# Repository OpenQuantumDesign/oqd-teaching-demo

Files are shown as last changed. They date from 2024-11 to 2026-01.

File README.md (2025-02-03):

# Open Quantum Design

<h2 align="center">
    Open Quantum Design: Full-stack Trapped-ion Teaching Demo  
</h2>

> [!NOTE]
> :bangbang: This design is still in the prototype stage - version 3 is under active development. Feel free to get in touch if you're interested in getting access to this teaching tool!

What is a trapped ion quantum computer? What are the components that go into building a quantum computer? What are the layers of a "full-stack"? What does it mean to "trap" an ion?

As quantum computers become increasingly widespread in the world, and as their capabilities advance, teaching an intuitive sense of how these machines work, what they are composed of, and how to interact with them is an important mission. At Open Quantum Design, we aim to democratize access to quantum computing technologies and accelerate a quantum-ready workforce and global community.

## Motivation

We want to provide a tactile and interactive activity for learning about, programming, and building quantum computers. This project contains the designs for a "trapped-ion quantum computer," using low-cost, easily accessible electronics.

## What's inside

The demo traps small beads of polystyrene in an acoustic trap, in analogy to ions in an electromagnetic trap, except visible to the naked eye and can be interacted with. Inexpensive diode lasers are added to demonstrate how the ions are manipulated using light. To demonstrate how the real trapped-ion system is measured using photodetectors, a camera module is included. A Raspberry Pi and Arduino Nano control all of these elements, and a touchscreen display provides a user interface. The enclosure is 3D printed and components assembled.

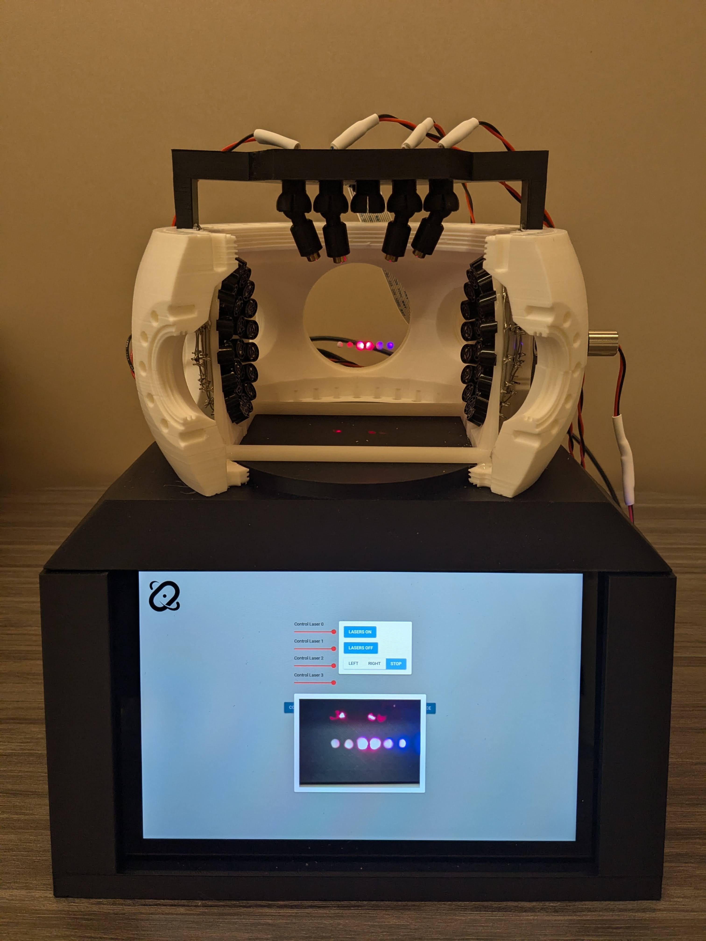
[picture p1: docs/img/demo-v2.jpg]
OQD Demo v2
# 

In the picture of the *version-2* design of the demo unit, six polystyrene balls are suspended in midair by sound. The pressure waves formed by an array of transducers at each end create points where objects are *suspended* in place by the force of the air. While OQD's quantum computers use an electromagnetic potential to trap the ions, the process is quite analogous - and you can actually see the polystyrene beads with your bare eyes, unlike ions! Red and blue lasers, shining onto the "ions," demonstrate how the state of the quantum computer is manipulated and how quantum algorithms are run.

## Want to build your own?

We love to hear that! The current version is still in the prototype stage, and *version-3* is currently in the works. But in this repository, you can find everything you need to build your own trapped ion outreach demo, including the designs, object files to 3D print, electronic wiring diagrams, and the control software.

- [3D printed enclosure components](./design/objects/)
- [Material list](./docs/materials.md)
- [Software](./src/)

## More about quantum computers

Quantum computers utilize the effects of quantum mechanics to process information. Some of the most important effects of quantum mechanics for computing purposes are superposition, entanglement, and measurement.

- **Superposition**: When a quantum particle can be in two distinct states, e.g., spin-up or spin-down, it can also exist in a superposition of those two states.
- **Entanglement**: When two or more quantum particles *interact* with one another, they can become entangled. Entanglement can be seen as two (or more) particles that are correlated in such a way that the state of one particle directly affects the state of the other, no matter the distance between them.
- **Measurement**: The act of measuring a quantum state forces it into one of the possible states, collapsing the superposition.

While classical computers are based on *bits*, information stored as 0s and 1s, quantum computers are based on *qubits*.

Quantum computers can be created using a variety of different underlying quantum systems. Some of the most popular directions that are being pursued include:

- **Atoms/ions**: Isolating individual atoms or ions. These are generally referred to as *trapped ion* or *neutral atom* quantum computers, respectively. These approaches differ in the methods for isolating and controlling the atoms.
- **Photons**: Individual particles, or quanta, of light can be used as the basic building blocks of a quantum computer.
- **Superconducting circuits**: These use superconducting materials to create qubits. Superconducting qubits are one of the most advanced and widely researched types of qubits, with companies like IBM and Google making significant progress in this area.
- **Spins**: Spin-based quantum computers use the spin of electrons or nuclei as qubits. This approach can leverage existing semiconductor technology, making it a promising direction for scalable quantum computing.

Each of these approaches has its own set of advantages and challenges, and research is ongoing to determine which will be the most practical and effective for large-scale quantum computing.

## Ion trap quantum computers

**Advantages of Ion Trap Quantum Computers**

- **Long coherence times**: Ions can remain in a quantum superposition for long times, allowing longer computations to be performed without error.
- **High fidelity operations**: Preparing and measuring the ions can be done to a very high degree of fidelity, which is crucial for accurate quantum computations.
- **All-to-all connectivity**: Trapped ion quantum devices can be made to have *all-to-all* connectivity. Other architectures are limited in which qubits can interact with which other qubits, often due to the physical layout of the device. Trapped ions can overcome this limitation, as the ions can be made to move, or 'shake', with other ions in very controlled ways.
- **Versatility**: Trapped ion systems can be used to simulate a wide range of quantum systems, making them versatile tools for quantum computing and simulation.

These advantages make ion trap quantum computers a promising direction for the development of practical and scalable quantum computing technologies.

Layers of a trapped ion quantum computer include:

- Vacuum chamber to trap ions
- Radiofrequency electrical probes to provide the trapping potential
- Laser system to control ions in the trap, including addressing the ions individually
- Real-time electronics control system
- Software stack enabling users to program the quantum computer

## References

- [1] Maslov, D., Nam, Y. & Kim, J. An Outlook for Quantum Computing [Point of View]. Proc. IEEE 107, 5–10 (2019).
- [2] Pogorelov, I. et al. Compact Ion-Trap Quantum Computing Demonstrator. PRX Quantum 2, 020343 (2021).
- [3] Blatt, R. & Wineland, D. Entangled states of trapped atomic ions. Nature 453, 1008–1015 (2008).
- [4] Shammah, N. et al. Open Hardware in Quantum Technology. Preprint at <https://doi.org/10.48550/arXiv.2309.17233> (2023).

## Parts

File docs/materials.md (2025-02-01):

# Version 2

Last updated: 2025-01-30

## Electronics

| Item | Links |
| --- | --- |
| Raspberry Pi 4B | [Raspberry Pi](https://www.raspberrypi.com/products/raspberry-pi-4-model-b/) |
| microSD card (8GB or above) | [Raspberry Pi](https://www.raspberrypi.com/products/sd-cards/) |
| 5 red diode dot lasers | [Amazon CA](https://www.amazon.ca/dp/B07XLDKW8R?ref=ppx_yo2ov_dt_b_fed_asin_title) |
| Raspberry Pi Camera Module 3 | [Raspberry Pi](https://www.raspberrypi.com/products/camera-module-3/) |
| 50cm ribbon cable for Raspberry Pi Camera | [Raspberry Pi](https://www.raspberrypi.com/products/camera-cable/) |
| 1 blue dot laser | [Amazon CA](https://www.amazon.ca/dp/B07B912MKK?ref=ppx_yo2ov_dt_b_fed_asin_title) |
| Raspberry Pi Touchscreen | [PiShop CA](https://www.pishop.ca/product/8inch-capacitive-touch-display-wide-color-gamut-1280-800-optical-bonding-toughened-glass-panel-hdmi-type-c-display-interface/) |
| On/Off LED Switch | [Adafruit](https://www.adafruit.com/product/915) |

 Note: Designs for the next version will use the official Raspberry Pi touchscreen.

## Enclosure Prints

| Item | Links | Details |
| --- | --- | --- |
| OQD Base Enclosure | [STL File](../design/objects/oqd-enclosure-base.stl) | |
| OQD Base Top | [STL File](../design/objects/oqd-enclosure-top-lid.stl) | |
| OQD Vacuum Top | [STL File](../design/objects/vacuum-top.stl) | |
| OQD Vacuum Bottom | [STL File](../design/objects/vacuum-bottom.stl) | |
| OQD Laser & Camera Mount | [STL File](../design/objects/camera-laser-rack.stl) | |
| OQD Laser Ball Joints | STL Files, [Holder](../design/objects/joint1.stl), [Socket](../design/objects/joint2.stl) | |
| OQD Axial Laser Holder | [STL Files](../design/objects/side-laser-holder.stl) | |
| OQD Electronics Plate | [STL Files](../design/objects/electronics-plate.stl) | |

Note: Designs for the next version are in the works, and will improve slight misalignment in printed pieces.

## Acoustic Trap

The trapping mechanism is based on the excellent, and incredibly fun,
design by Asier Marzo, Adrian Barnes, Bruce W. Drinkwater and the UpnaLab.
Read the [Instructable](https://www.instructables.com/Acoustic-Levitator/)
and the [journal publication](https://doi.org/10.1063/1.4989995).

Please read through their detailed explanation on how to build the acoustic levitator.

| Item | Links |
| --- | ----- |
| Arduino Nano | |
| 72 Transducers | |
| L297N Driver | |
| Switch | |
| Printed TinyLev | |
| Jumper wires | |
| 12AWG black and red wire | |
| Polystyrene beads (to levitate!) | |

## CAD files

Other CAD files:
design/objects/oqd-enclosure-base.stl
design/objects/camera-laser-rack.stl
design/objects/joint1.stl
design/objects/side-laser-holder.stl
design/objects/vacuum-bottom.stl
design/objects/electronics-plate.stl
design/objects/vacuum-top.stl
design/objects/oqd-enclosure-top-lid.stl
design/objects/joint2.stl

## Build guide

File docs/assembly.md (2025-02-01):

# Assembly of the demo

1. **Build the acoustic trap**
   1. Source all materials and 3D print components, see [Materials](./materials.md).
   2. Follow the [Instructable](https://www.instructables.com/Acoustic-Levitator/) and the [journal publication](https://doi.org/10.1063/1.4989995) to assemble the acoustic trap apparatus.

2. **3D print the enclosure**
   1. Print all objects provided as STL files in the [`design/objects`](../design/objects/) folder.
   2. Install the on/off switch on the right-hand side of the bottom enclosure, and connect it to a power source.

3. **Connect the lasers, trap, and camera**
   1. Connect the [holder](../design/objects/joint1.stl) and [socket](../design/objects/joint2.stl) of the ball joint. Insert one red laser into each holder, thread the wires through both the holder and socket, and solder wire extensions so that the lasers can be powered from the Raspberry Pi (~30cm of wire). Use hot glue to secure the lasers in the holder.
   2. Connect the negative wire for the red lasers to the Raspberry Pi ground pin and the positive wires to the GPIO pins as described in the [wiring diagram](../design/wiring.fzz).
   3. Connect the grounds between the Raspberry Pi and Arduino Nano, so they share a common ground.
   4. Connect the Raspberry Pi GPIO pins to the Arduino Nano pins to control the acoustic trap motion, as in the [wiring diagram](../design/wiring.fzz).
   5. Connect the camera ribbon cable to the camera and Raspberry Pi.

4. **Set up the software**
   1. Flash the SD card with [Raspberry Pi OS](https://www.raspberrypi.com/software/) and insert it into the Raspberry Pi.
   2. Connect the touchscreen to the Raspberry Pi.
   3. Boot up the Raspberry Pi, and clone the repository to the device.

        ```bash
        git clone https://github.com/OpenQuantumDesign/outreach.git
        ```

   4. Install a code editor, such as Visual Studio Code (e.g., `sudo apt install code`).
   5. Create a virtual environment, e.g., with `pip` or `venv`, and install all dependencies.
   6. Ensure the device configuration matches the GPIO pins used for the trap and laser.
   7. Test that images are correctly captured by the camera, and that the laser intensities and trap positions are controllable via the software modules.

        ```bash
        # activate the virtual environment
        source .venv/bin/activate

        # start the camera stream and detach
        python src/gui/camera_stream.py &

        # start the main interface server
        python src/gui/main.py &
        ```

   8. Launch a browser in kiosk mode

        ```bash
        chromium --kiosk http://127.0.0.1:8080
        ```

5. **Put it all together:**
   1. Once everything is tested and working, package it into the 3D printed enclosure, using the electronics plate to screw down, e.g., the Raspberry Pi, Arduino Nano, and driver.
   2. Have fun teaching about trapped ion quantum computers!

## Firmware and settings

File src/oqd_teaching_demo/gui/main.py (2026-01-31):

from nicegui import ui
import threading
import atexit
import sys
import logging

from oqd_teaching_demo.program import Program
from oqd_teaching_demo.gui.programs import digital_shor, digital_random, analog_ising, analog_all_to_all

# For development & testing (i.e., unitaryDESIGN participants!), set this MOCK = True
MOCK = True

if MOCK:
    from oqd_teaching_demo.control.mock import MockDevice as Device
    stream_ip = 'docs/img/bloodstone.jpg'
else:
    from oqd_teaching_demo.control.device import Device as Device
    stream_ip = 'http://127.0.0.1:5000/stream'

class Board:
    _instance = None

    def __new__(cls, *args, **kwargs):
        if cls._instance is None:
            logging.info("Creating new GpioControl instance")
            cls._instance = super(Board, cls).__new__(cls)
            cls._instance._initialize_gpio(*args, **kwargs)
        else:
            logging.info("Reusing existing Board instance")
        return cls._instance

    def _initialize_gpio(self):
        self.device = Device()
        logging.info(f"Device initialized")

    def cleanup(self):
        return


def control_card(board: Board):
    with ui.dialog() as control_dialog, ui.card():
        ui.label('Control Panel').style('color: #6E93D6; font-size: 200%; font-weight: 300')

        with ui.row().classes('fixed-center'):


            with ui.list().classes('w-32'):
                sliders = {}
                for i in range(len(board.device.red_lasers.channels)):
                    ui.label(f"Control Laser {i}")
                    slider = ui.slider(
                        min=0.0, max=1.0, step=0.01, value=0.5, 
                        # on_change=lambda value, idx=i: device.red_lasers_set_intensity(idx=idx, intensity=value)
                    ).props('color=red').on('change', lambda e, idx=i: board.device.red_lasers.set_intensity(idx=idx, intensity=e.args))
                    sliders[i] = slider
                    slider.value = 0.0
                
                def all_on():
                    for idx, slider in sliders.items():
                        slider.value = 1.0
                        board.device.red_lasers.set_intensity(idx=idx, intensity=1.0)

                def all_off():
                    for idx, slider in sliders.items():
                        slider.value = 0.0
                        board.device.red_lasers.set_intensity(idx=idx, intensity=0.0)

            with ui.card():
                ui.button('Lasers On', on_click=all_on)
                ui.button('Lasers Off', on_click=all_off)


                toggle = ui.toggle(
                    {
                        'left': 'Left', 
                        'right': 'Right', 
                        'stop': 'Stop',
                        # 'shake': 'Shake', 
                    }, 
                    on_change=lambda e: board.device.trap.mode(e.value)
                )
                toggle.value = "stop"


            with ui.card().classes('w-full'):
                ui.image(stream_ip)#.classes('w-full h-auto')

        return control_dialog



def digital_card(board: Board):
    with ui.dialog() as digital_dialog, ui.card():
        with ui.row().classes('fixed-center'):
            with ui.list():
                ui.button("Shor's Algorithm", on_click=lambda: board.device.run(digital_shor())).props('border p-33')
                ui.button("Random Circuit", on_click=lambda: board.device.run(digital_random())).props('border p-3')

            with ui.card().classes('w-full'):
                ui.image(stream_ip)

    return digital_dialog
    

def analog_card(board: Board):
    with ui.dialog() as analog_dialog, ui.card():
        with ui.row().classes('fixed-center'):
            with ui.list():
                ui.button("Nearest Neighbours Ising", on_click=lambda: board.device.run(analog_ising()))
                ui.button("All-to-All Interactions", on_click=lambda: board.device.run(analog_all_to_all()))


            with ui.card().classes('w-full'):
                ui.image(stream_ip)

    return analog_dialog


def main():

    board = Board()
    atexit.register(board.cleanup)

    

    control_dialog = control_card(board)
    digital_dialog = digital_card(board)
    analog_dialog = analog_card(board)

    with ui.column():
        with ui.row().classes('fixed-center'):
            ui.button('Control Panel', on_click=control_dialog.open)
            ui.button('Digital Interface', on_click=digital_dialog.open)
            ui.button('Analog Interface', on_click=analog_dialog.open)

        ui.image("https://github.com/OpenQuantumDesign/equilux/blob/9ed0c5380133e7d135121c44c3f4cdbcb8cf781b/docs/img/oqd-logo.png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").classes("w-32 h-32")



# Start the NiceGUI app
if __name__ in {"__main__", "__mp_main__"}:
    main()
    ui.run(
        title='Physics Demo Control',
        host='0.0.0.0',
        port=8080,
        reload=False,
        favicon="https://github.com/OpenQuantumDesign/equilux/blob/9ed0c5380133e7d135121c44c3f4cdbcb8cf781b/docs/img/oqd-logo.png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",
    )

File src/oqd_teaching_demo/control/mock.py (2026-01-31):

# Copyright 2024-2025 Open Quantum Design

# Licensed under the Apache License, Version 2.0 (the "License");
# you may not use this file except in compliance with the License.
# You may obtain a copy of the License at

#     http://www.apache.org/licenses/LICENSE-2.0

# Unless required by applicable law or agreed to in writing, software
# distributed under the License is distributed on an "AS IS" BASIS,
# WITHOUT WARRANTIES OR CONDITIONS OF ANY KIND, either express or implied.
# See the License for the specific language governing permissions and
# limitations under the License.

"""
Mock implementations of hardware control classes for testing without physical hardware.

These classes provide the same interface as the real hardware classes but print
actions instead of controlling GPIO pins, lasers, or cameras.
"""

from pydantic import BaseModel, Field
from pydantic.types import NonNegativeInt
from typing import Literal
import time
import threading
import numpy as np


class MockTrap(BaseModel):
    """Mock implementation of the acoustic trap controller."""

    pin_left: int = 20
    pin_right: int = 16
    pin_reset: int = 21
    frequency: float = 1
    duty: float = 50

    def model_post_init(self, _context=None):
        self._current_mode = "stop"
        print(f"[MockTrap] Initialized with pins: left={self.pin_left}, right={self.pin_right}, reset={self.pin_reset}")

    def left(self):
        self._current_mode = "left"
        print("[MockTrap] Moving trap LEFT")

    def right(self):
        self._current_mode = "right"
        print("[MockTrap] Moving trap RIGHT")

    def stop(self):
        self._current_mode = "stop"
        print("[MockTrap] Trap STOPPED")

    def shake(self):
        self._current_mode = "shake"
        print(f"[MockTrap] Trap SHAKING at frequency={self.frequency}Hz, duty={self.duty}%")

    def mode(self, mode: Literal["left", "right", "shake", "stop"]):
        if mode == "left":
            self.left()
        elif mode == "right":
            self.right()
        elif mode == "shake":
            self.shake()
        elif mode == "stop":
            self.stop()
        else:
            print(f"[MockTrap] Unknown mode: {mode}")

    def close(self):
        print("[MockTrap] Closing trap controller")
        self._current_mode = "stop"


class MockLaserArray(BaseModel):
    """Mock implementation of the laser array controller."""

    channels: list[int] = []

    def model_post_init(self, _context=None):
        self._intensities = {channel: 0.0 for channel in self.channels}
        print(f"[MockLaserArray] Initialized with channels: {self.channels}")

    def set_intensities(self, intensities: list):
        for j, channel in enumerate(self.channels):
            self.set_intensity(idx=j, intensity=intensities[j])

    def set_intensity(self, idx: int, intensity: float):
        channel = self.channels[idx]
        self._intensities[channel] = intensity
        print(f"[MockLaserArray] Channel {channel} (idx={idx}) intensity set to {intensity:.2f}")

    def waveform(self, intensities: np.array, dt: float):
        print(f"[MockLaserArray] Playing waveform with {intensities.shape[0]} steps, dt={dt}s")
        for i in range(intensities.shape[0]):
            for j, channel in enumerate(self.channels):
                self._intensities[channel] = intensities[i, j]
            time.sleep(dt)
        print("[MockLaserArray] Waveform complete")

    def on(self):
        print("[MockLaserArray] All lasers ON (intensity=1.0)")
        for channel in self.channels:
            self._intensities[channel] = 1.0

    def off(self):
        print("[MockLaserArray] All lasers OFF")
        for channel in self.channels:
            self._intensities[channel] = 0.0


class MockRedLasers(MockLaserArray):
    """Mock implementation of red laser array."""

    channels: list[int] = [5, 6, 19, 26]

    def model_post_init(self, _context=None):
        self._intensities = {channel: 0.0 for channel in self.channels}
        print(f"[MockRedLasers] Initialized with channels: {self.channels}")


class MockGreenLaser(MockLaserArray):
    """Mock implementation of green laser."""

    channels: list[int] = [2]

    def model_post_init(self, _context=None):
        self._intensities = {channel: 0.0 for channel in self.channels}
        print(f"[MockGreenLaser] Initialized with channels: {self.channels}")


class MockBlueLaser(MockLaserArray):
    """Mock implementation of blue laser."""

    channels: list[int] = [3]

    def model_post_init(self, _context=None):
        self._intensities = {channel: 0.0 for channel in self.channels}
        print(f"[MockBlueLaser] Initialized with channels: {self.channels}")


class MockCamera(BaseModel):
    """Mock implementation of the Raspberry Pi camera."""

    transform: Literal["none", "horizontal", "vertical", "both"] = "none"
    exposure_time: NonNegativeInt = 30000
    analog_gain: float = 1.0

    def model_post_init(self, _context=None):
        print(f"[MockCamera] Initialized with transform={self.transform}, exposure_time={self.exposure_time}, analog_gain={self.analog_gain}")

    def capture(self, file: str = "image"):
        print(f"[MockCamera] Capturing image to {file}.png")


class MockDevice(BaseModel):
    """Mock implementation of the main device controller."""

    trap: MockTrap = Field(default_factory=MockTrap)
    red_lasers: MockRedLasers = Field(default_factory=MockRedLasers)
    blue_laser: MockBlueLaser = Field(default_factory=MockBlueLaser)

    def model_post_init(self, _context=None):
        self._stop_event = threading.Event()
        print("[MockDevice] Device initialized")

    def stop(self):
        print("[MockDevice] Stopping task...")
        self._stop_event.set()

    def run(self, program):
        print(f"[MockDevice] Running program with {len(program)} steps")
        for i in range(len(program)):
            if self._stop_event.is_set():
                print("[MockDevice] Program interrupted.")
                break
            self.red_lasers.set_intensities(intensities=program.red_lasers_intensity[i])
            time.sleep(program.dt)

        self.red_lasers.off()
        print("[MockDevice] Program complete")
        return


if __name__ == "__main__":
    print("=== Testing MockDevice ===\n")

    device = MockDevice()

    print("\n--- Testing trap modes ---")
    device.trap.left()
    device.trap.right()
    device.trap.shake()
    device.trap.stop()

    print("\n--- Testing laser control ---")
    device.red_lasers.set_intensity(idx=0, intensity=0.5)
    device.red_lasers.on()
    device.red_lasers.off()

    print("\n--- Testing blue laser ---")
    device.blue_laser.on()
    device.blue_laser.off()

    print("\n=== Mock tests complete ===")

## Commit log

2024-04-30 Added API request to run experiment on the PYNQ board
2024-08-28 Add trap position control and PWM laser intensity control
2024-08-28 Use gpiozero for laser PWM
2024-09-10 Add Fritz wiring file
    [wiring.fzz]
2024-09-27 Tweaks to control laser classes
2024-09-28 Add device, test threading UI
2024-09-28 Test camera and blue laser
2024-09-28 Add program IR, test devices
2024-09-29 Add camera stream to GUI
2024-11-27 Add material list
2024-11-27 Add v2 object files
    [camera-laser-rack.stl, electronics-plate.stl, joint1.stl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]
2025-01-30 Update BoM, copyrights
2025-01-30 Update materials, assembly instructions, and README
2026-01-31 Fix paths on demo unit
    [device.py, main.py]
2026-07-22 Wire up circuit builder dialog
2026-07-22 Proxy camera stream through main UI port
